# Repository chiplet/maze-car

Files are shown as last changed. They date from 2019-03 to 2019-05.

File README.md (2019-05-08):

# maze-car
This repository contains the example code for the Mazeblazer game. 

The full game instructions and a more detailed getting started guide are available at:
https://docs.google.com/document/d/1SaZNl0VVnFEm_aR2c8GMJGQdpziAJxaRw1_wqC6xl4o/edit?usp=sharing

## Getting Started
1. Download the code from this repository to your computer
- Download git for windows/linux/macOS from https://git-scm.com/downloads
- Use command `git clone https://github.com/VerkkuUkkeli/maze-car` to download a copy of the repository to your machine
2. Download and install the Arduino IDE from https://www.arduino.cc/en/Main/Software
3. Install the following Arduino libraries from Sketch -> Include Library -> Manage Libraries menu in the arduino IDE
- Adafruit Unified Sensor
- Adafruit LSM303DLHC
4. Tell the Arduino IDE what board is being used from the Tools menu
- Board: Arduino Nano
- Processor: ATmega328P (Old Bootloader)
- Port: wchusbserial

## Software
- `main.ino` contains the arduino setup and loop code. Write your maze solving application into this file.
- `helpers.ino` contains helper functions for interfacing with the car hardware.

## Hardware
The provided code already takes care of interfacing with the hardware. If you for whatever reason want to write code for interfacing with the hardware directly you are welcome to do so. The components used in the car are listed below.

- Arduino Nano
- Motor driver - [TB6612FNG](https://learn.sparkfun.com/tutorials/tb6612fng-hookup-guide)
- 2 motors
- 5 custom IR distance sensors
- Magnetometer - LSM303DLHC

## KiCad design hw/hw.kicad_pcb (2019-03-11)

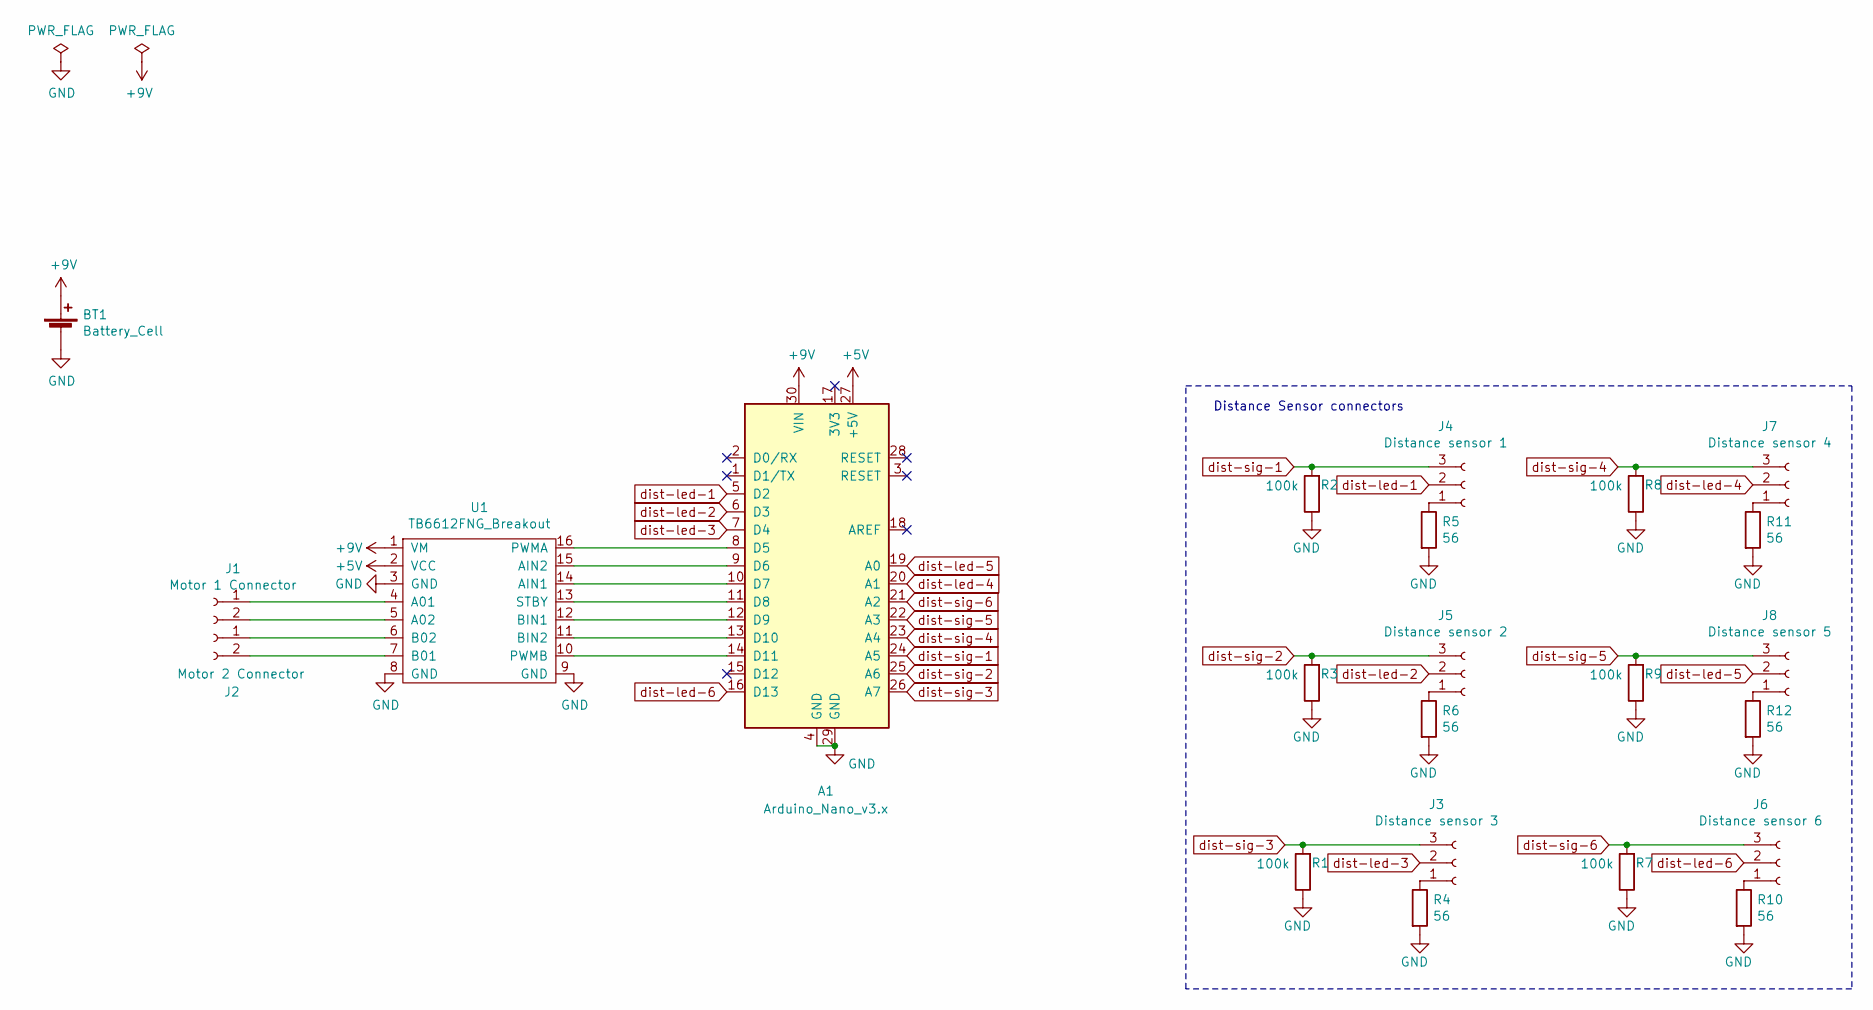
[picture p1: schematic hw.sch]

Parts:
A1: Arduino_Nano_v3.x; Arduino_Nano
BT1: Battery_Cell; PinSocket_1x02_P2.54mm_Vertical
J1: Motor 1 Connector; PinSocket_1x02_P2.54mm_Vertical
J2: Motor 2 Connector; PinSocket_1x02_P2.54mm_Vertical
J3: Distance sensor 3; PinSocket_1x03_P2.54mm_Vertical
J4: Distance sensor 1; PinSocket_1x03_P2.54mm_Vertical
J5: Distance sensor 2; PinSocket_1x03_P2.54mm_Vertical
J6: Distance sensor 6; PinSocket_1x03_P2.54mm_Vertical
J7: Distance sensor 4; PinSocket_1x03_P2.54mm_Vertical
J8: Distance sensor 5; PinSocket_1x03_P2.54mm_Vertical
R1, R2, R3, R7, R8, R9: 100k; R_Axial_DIN0207_L6.3mm_D2.5mm_P7.62mm_Horizontal
R4, R5, R6, R10, R11, R12: 56; R_Axial_DIN0207_L6.3mm_D2.5mm_P7.62mm_Horizontal
U1: TB6612FNG_Breakout; TB6612FNG breakout

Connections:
+5V: A1.27 (+5V), U1.2 (VCC)
+9V: A1.30 (VIN), BT1.1 (+), U1.1 (VM)
GND: A1.4 (GND), A1.29 (GND), BT1.2 (-), R1.1, R2.1, R3.1, R4.2, R5.2, R6.2, R7.1, R8.1, R9.1, R10.2, R11.2, R12.2, U1.3 (GND), U1.8 (GND), U1.9 (GND)
unnamed: A1.8 (D5), U1.16 (PWMA)
unnamed: A1.9 (D6), U1.15 (AIN2)
unnamed: A1.10 (D7), U1.14 (AIN1)
unnamed: A1.11 (D8), U1.13 (STBY)
unnamed: A1.12 (D9), U1.12 (BIN1)
unnamed: A1.13 (D10), U1.11 (BIN2)
unnamed: A1.14 (D11), U1.10 (PWMB)
unnamed: J1.1, U1.4 (A01)
unnamed: J1.2, U1.5 (A02)
unnamed: J2.1, U1.6 (B02)
unnamed: J2.2, U1.7 (B01)
unnamed: J3.1, R4.1
unnamed: J4.1, R5.1
unnamed: J5.1, R6.1
unnamed: J6.1, R10.1
unnamed: J7.1, R11.1
unnamed: J8.1, R12.1
dist-led-1: A1.5 (D2), J4.2
dist-led-2: A1.6 (D3), J5.2
dist-led-3: A1.7 (D4), J3.2
dist-led-4: A1.20 (A1), J7.2
dist-led-5: A1.19 (A0), J8.2
dist-led-6: A1.16 (D13), J6.2
dist-sig-1: A1.24 (A5), J4.3, R2.2
dist-sig-2: A1.25 (A6), J5.3, R3.2
dist-sig-3: A1.26 (A7), J3.3, R1.2
dist-sig-4: A1.23 (A4), J7.3, R8.2
dist-sig-5: A1.22 (A3), J8.3, R9.2
dist-sig-6: A1.21 (A2), J6.3, R7.2

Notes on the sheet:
Distance Sensor connectors

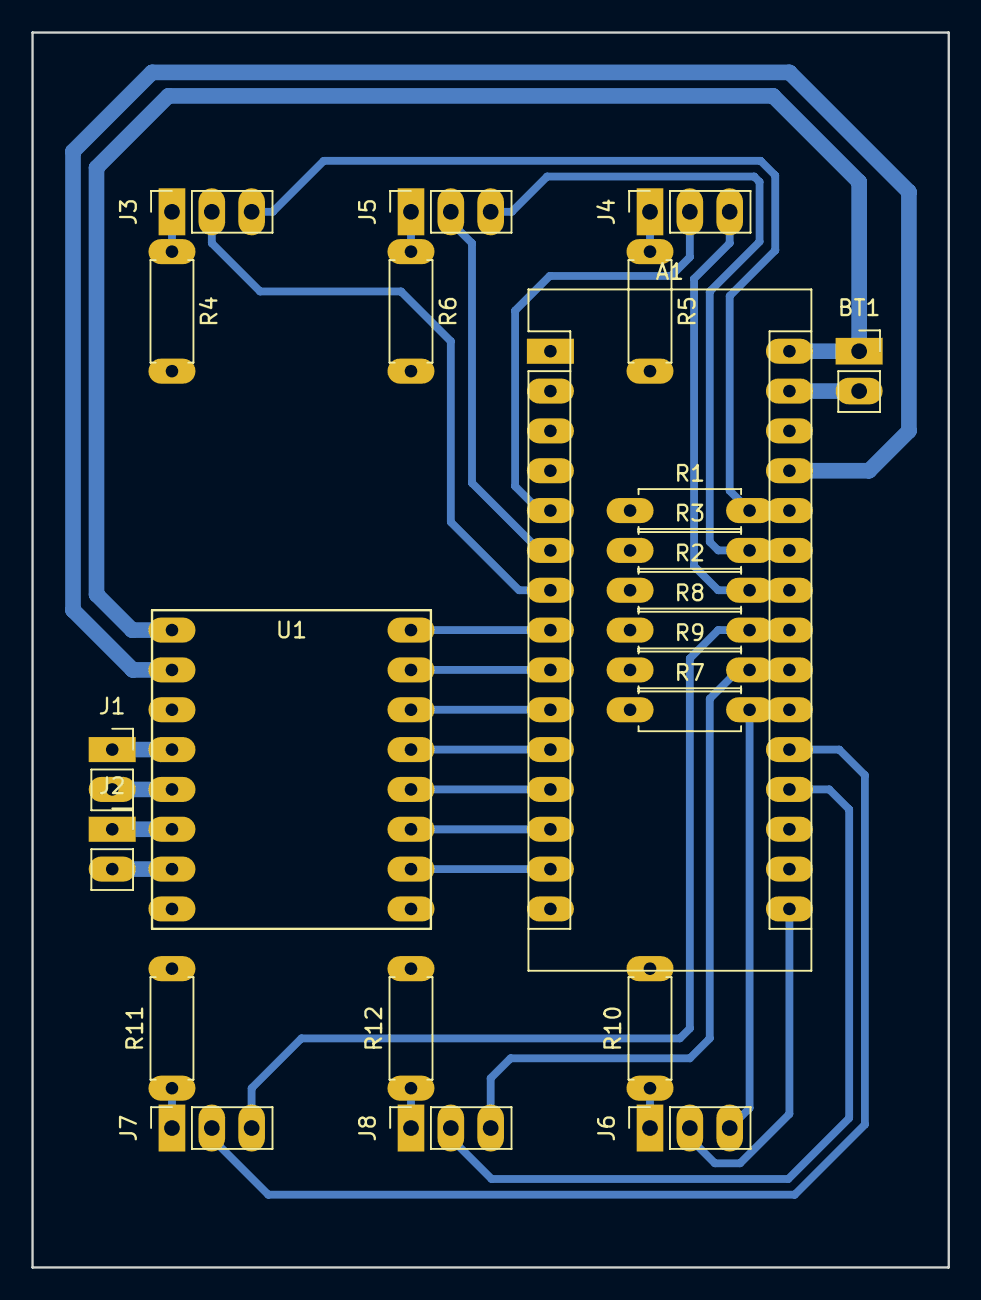
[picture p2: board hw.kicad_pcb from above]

Board: 2 copper layers, 58.4 x 78.7 mm, 23 parts (0 on the bottom side), 32 nets.

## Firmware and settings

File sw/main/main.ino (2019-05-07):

/* includes */
#include <Wire.h>
#include <Adafruit_Sensor.h>
#include <Adafruit_LSM303_U.h>

/* pin definitions */
// motor controller
#define PWMA 5
#define AIN2 6
#define AIN1 7
#define STBY 8
#define BIN1 9
#define BIN2 10
#define PWMB 11

// distance sensor IR leds
#define DIST_LED_1 2
#define DIST_LED_2 3
#define DIST_LED_3 4
#define DIST_LED_4 12
#define DIST_LED_5 13

// distance sensor signal pins
#define DIST_SIG_1 A0
#define DIST_SIG_2 A1
#define DIST_SIG_3 A2
#define DIST_SIG_4 A6
#define DIST_SIG_5 A7

/* Assign a unique ID to this sensor at the same time */
Adafruit_LSM303_Mag_Unified mag = Adafruit_LSM303_Mag_Unified(12345);

/* pin number arrays for convenience */
// distance sensor signal pins
const int sensor_pins[] = {DIST_SIG_1, DIST_SIG_2, DIST_SIG_3, DIST_SIG_4, DIST_SIG_5};
const int n_sensor_pins = sizeof(sensor_pins)/sizeof(sensor_pins[0]);

// distance sensor LED pins
const int led_pins[] = {DIST_LED_1, DIST_LED_2, DIST_LED_3, DIST_LED_4, DIST_LED_5};
const int n_led_pins = sizeof(led_pins)/sizeof(led_pins[0]);

// array for holding latest distance sensor readings
int sensor_readings[n_sensor_pins] = {0};

enum motors
{
  M_LEFT,
  M_RIGHT
};

int ain1 = 1;
int ain2 = 0;
int bin1 = 1;
int bin2 = 0;

void setup() {
  /* configure timer interrupt */
  // disable interrupts
  cli();

  // set timer1 to interrupt at 8*60 Hz
  TCCR1A = 0;
  TCCR1B = 0;
  TCNT1  = 0;  // init counter to 0
  // set compare match register for 60hz increments
  // OCR1A = 33332; // = (16*10^6) / (1*8) - 1 (must be <65536)
  OCR1A = 2499; // = (16*10^6) / (1*8) - 1 (must be <65536)
  // turn on CTC mode
  TCCR1B |= (1 << WGM12);
  // Set CS11 bit for 8 prescaler
  TCCR1B |= (1 << CS11);  
  // enable timer compare interrupt
  TIMSK1 |= (1 << OCIE1A);

  // enable interrupts
  sei();


  /* Serial debug connection */
  Serial.begin(115200);

  /* initialise GPIO pins */
  for (int i = 0; i < n_sensor_pins; i++)
  {
    pinMode(sensor_pins[i], INPUT);
  }

  for (int i = 0; i < n_led_pins; i++)
  {
    pinMode(led_pins[i], OUTPUT);
  }
  
  digitalWrite(AIN1, ain1);
  digitalWrite(AIN2, ain2);
  digitalWrite(BIN1, bin1);
  digitalWrite(BIN2, bin2);
  digitalWrite(STBY, HIGH);

  /* initialise magnetometer */
  // enable auto gain
  mag.enableAutoRange(true);
  
  if(!mag.begin())
  {
    Serial.println("Ooops, no LSM303 detected ... Check your wiring!");
    while(1);
  }
}

void loop() {
  /*** WRITE YOUR MAZE SOLVING APPLICATION CODE HERE ***/

  // simple example which uses the front sensor to detect obstacles and change direction
  /*
  if (get_distance_sensor(1) > 700)
  {
    set_motor_speed(M_LEFT, 0.0f);
    set_motor_speed(M_RIGHT, 0.0f);
    delay(1000);
    set_motor_speed(M_LEFT, 0.4f);
    set_motor_speed(M_RIGHT, -0.4f);
    delay(300);
    set_motor_speed(M_LEFT, 0.0f);
    set_motor_speed(M_RIGHT, 0.0f);
    delay(1000);
    set_motor_speed(M_LEFT, 0.25f);
    set_motor_speed(M_RIGHT, 0.25f);
  }
  else
  {
    set_motor_speed(M_LEFT, 0.25f);
    set_motor_speed(M_RIGHT, 0.25f);
  }
  delay(5);
  */
}

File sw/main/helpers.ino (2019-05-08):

// global variables used by the helper functions
unsigned int current_sensor = 0;  // used by the timer interrupt service routine to update sensor readings

// print latest distance sensor readings using the Serial connection
void print_sensors()
{
  for (int i = 0; i < n_sensor_pins; i++)
  {
    Serial.print(String() + sensor_readings[i] + ", ");
  }
}

// print magnetometer sensor details using the Serial connection
void displaySensorDetails(void)
{
  sensor_t sensor;
  mag.getSensor(&sensor);
  Serial.println("------------------------------------");
  Serial.print  ("Sensor:       "); Serial.println(sensor.name);
  Serial.print  ("Driver Ver:   "); Serial.println(sensor.version);
  Serial.print  ("Unique ID:    "); Serial.println(sensor.sensor_id);
  Serial.print  ("Max Value:    "); Serial.print(sensor.max_value); Serial.println(" uT");
  Serial.print  ("Min Value:    "); Serial.print(sensor.min_value); Serial.println(" uT");
  Serial.print  ("Resolution:   "); Serial.print(sensor.resolution); Serial.println(" uT");
  Serial.println("------------------------------------");
  Serial.println("");
  delay(500);
}

// set given motor to spin at given rate
// positive values -> forward, negative values -> backward
void set_motor_speed(enum motors motor, float value)
{  
  // restrict value to range [-1, 1]
  if (value < -1.0f) value = -1.0f;
  if (value > 1.0f) value = 1.0f;

  // pin states for forward movement
  int ain1 = 0;
  int ain2 = 1;
  int bin1 = 0;
  int bin2 = 1;

  if (motor == M_RIGHT)
  {
    value += 0.04; // increase right motor speed to compensate for turning
    if (value < 0)
    {
      ain1 = !ain1;
      ain2 = !ain2;
      value = 1 - value;
    }
    digitalWrite(AIN1, ain1);
    digitalWrite(AIN2, ain2);
    analogWrite(PWMA, value * 255);
  }

  if (motor == M_LEFT)
  {
    if (value < 0)
    {
      bin1 = !bin1;
      bin2 = !bin2;
      value = 1 - value;
    }
    digitalWrite(BIN1, bin1);
    digitalWrite(BIN2, bin2);
    analogWrite(PWMB, value * 255);
  }
}

// get the latest measurement from the distance sensor with index index
// returns -1 on failure
int get_distance_sensor(int index)
{
  if (index < 0 || index >= 5)
  {
    Serial.println("Error! Distance sensor index out of bounds! Index needs to be a value between 0 and 4.");
    return -1;
  }
  return sensor_readings[index];
}

// read magnetometer x component
float get_magnetometer_x()
{
  sensors_event_t event;
  mag.getEvent(&event);

  float mx = event.magnetic.x;
  return mx;
}

// read magnetometer y component
float get_magnetometer_y()
{
  sensors_event_t event;
  mag.getEvent(&event);

  float my = event.magnetic.y;
  return my;
}

// read magnetometer z component
float get_magnetometer_z()
{
  sensors_event_t event;
  mag.getEvent(&event);

  float mz = event.magnetic.z;
  return mz;
}

// timer interrupt service routine for updating sensor readings
ISR(TIMER1_COMPA_vect)
{
  // turn current sensor on
  digitalWrite(led_pins[current_sensor], HIGH);
  delay(1);

  // read current sensor
  sensor_readings[current_sensor] = analogRead(sensor_pins[current_sensor]);

  // turn current sensor off
  digitalWrite(led_pins[current_sensor], LOW);

  current_sensor++;

  // select sensor to be used
  if (current_sensor >= 5) current_sensor = 0;
}

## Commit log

2019-03-05 Added motor control test script
2019-03-06 Added sensor connectors
    [hw.kicad_pcb, hw.sch]
2019-03-06 Added resistors for distance sensors. Added motor driver and shift register for more output
    [hw.kicad_pcb, hw.sch]
2019-03-06 Saved schematic file
    [hw.sch]
2019-03-08 Laid out PCB footprints
    [hw.kicad_pcb, hw.sch]
2019-03-11 Modified pads
    [hw.kicad_pcb]
2019-03-12 Added helper function for driving motors
2019-05-03 Modified software to support sensors for the new hardware
2019-05-03 Added magnetometer code
2019-05-08 fixed sensor index typo
    [helpers.ino]
